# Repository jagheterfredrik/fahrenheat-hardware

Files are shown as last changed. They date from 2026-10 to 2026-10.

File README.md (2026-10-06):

# fahrenheat-hardware

A hat for the ESP32-C3 SuperMini that adds CAN-FD and 12 V input. [Firmware](https://github.com/jagheterfredrik/fahrenheat) written on Zephyr.

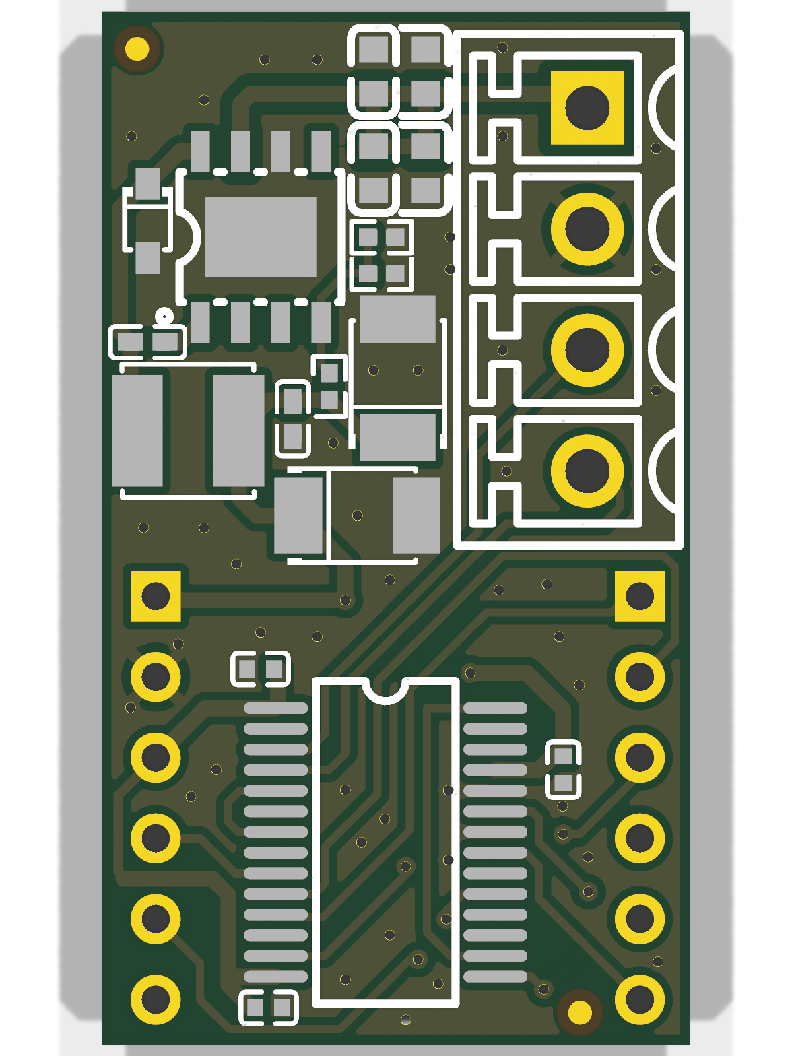
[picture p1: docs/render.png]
PCB render


- **CAN:** MCP251863 (CAN FD controller + transceiver) over SPI
- **Power:** TPS5430 buck, VCC in → 5 V to the SuperMini
- **CN1:** 3.81 mm terminal — VCC, GND, CANL, CANH

## Ordering

All parts carry LCSC numbers. `python3 export_jlcpcb.py` writes gerbers, BOM and CPL to `jlcpcb/` for JLCPCB assembly.

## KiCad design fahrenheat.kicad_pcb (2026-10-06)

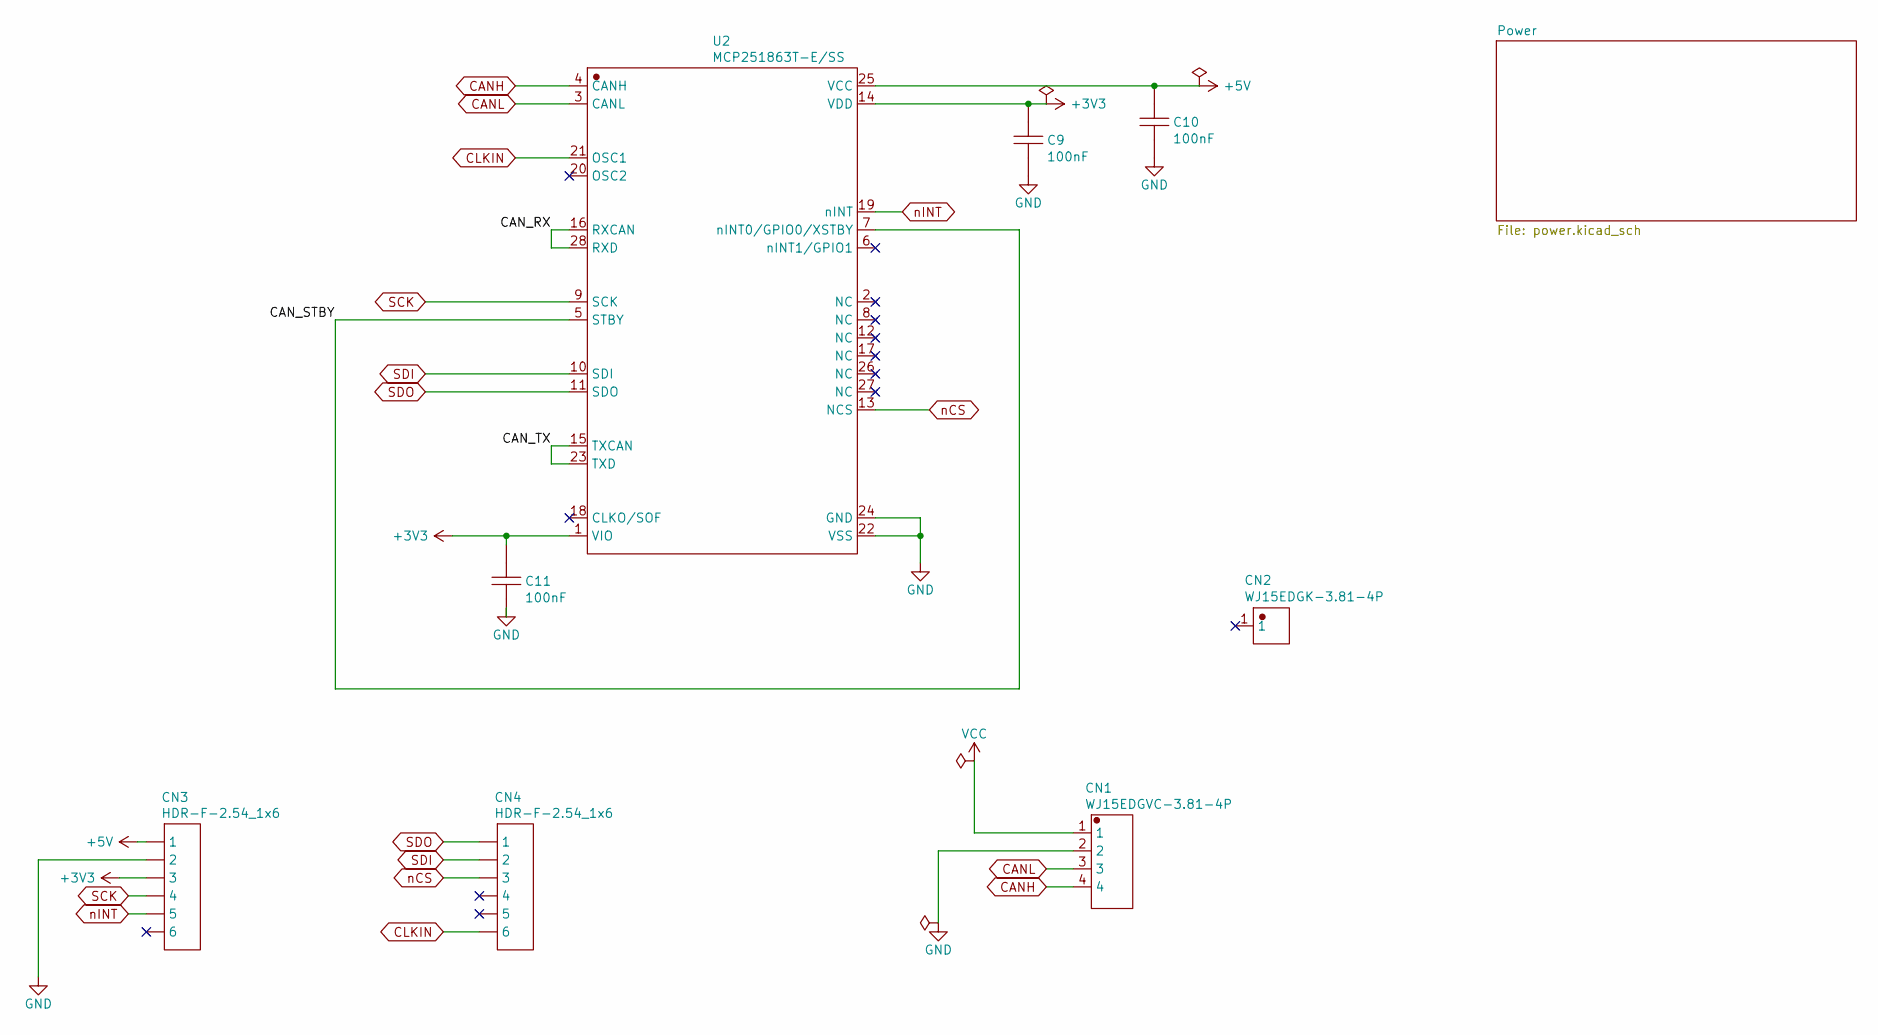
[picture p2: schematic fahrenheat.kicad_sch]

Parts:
C9, C10, C11: 100nF; C0402; MPN CL05B104KO5NNNC; LCSC C1525
CN1: WJ15EDGVC-3.81-4P; CONN-TH_4P-P3.81_WJ2EDGVC-3.81-4P; MPN WJ15EDGVC-3.81-4P; LCSC C8410
CN2: WJ15EDGK-3.81-4P; MPN WJ15EDGK-3.81-4P; LCSC C7244
CN3, CN4: HDR-F-2.54_1x6; HDR-F-2.54_1X6; LCSC C40877
U2: MCP251863T-E/SS; SSOP-28_L10.2-W5.3-P0.65-LS7.8-BL; MPN MCP251863T-E/SS; LCSC C5226885

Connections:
+3V3: C9.2, C11.2, CN3.3, U2.1 (VIO), U2.14 (VDD)
+5V: C10.2, CN3.1, U2.25 (VCC); also elsewhere on the board
/MCU_CAN/CAN_RX: U2.16 (RXCAN), U2.28 (RXD)
/MCU_CAN/CAN_STBY: U2.5 (STBY), U2.7 (nINT0/GPIO0/XSTBY)
/MCU_CAN/CAN_TX: U2.15 (TXCAN), U2.23 (TXD)
CANH: CN1.4, U2.4 (CANH)
CANL: CN1.3, U2.3 (CANL)
CLKIN: CN4.6, U2.21 (OSC1)
GND: C9.1, C10.1, C11.1, CN1.2, CN3.2, U2.22 (VSS), U2.24 (GND); also elsewhere on the board
SCK: CN3.4, U2.9 (SCK)
SDI: CN4.2, U2.10 (SDI)
SDO: CN4.1, U2.11 (SDO)
VCC: CN1.1; also elsewhere on the board
nCS: CN4.3, U2.13 (NCS)
nINT: CN3.5, U2.19 (nINT)

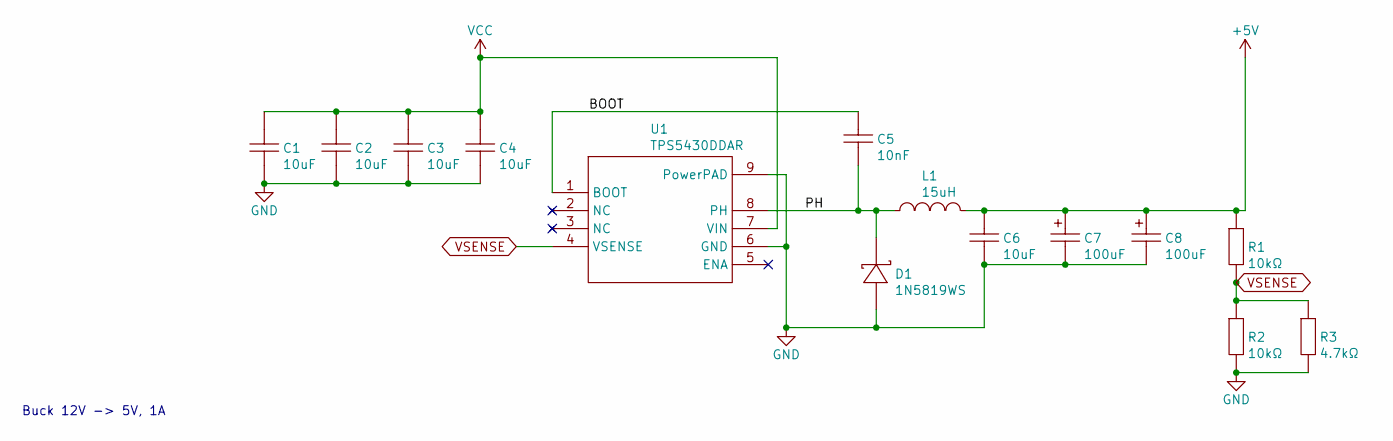
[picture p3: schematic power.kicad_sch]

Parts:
C1, C2, C3, C4: 10uF; C0603; MPN CL10A106MA8NRNC; LCSC C96446
C5: 10nF; C0402_LongPad; MPN CL05B103KB5NNNC; LCSC C15195
C6: 10uF; C0402_LongPad; MPN CL05A106MQ5NUNC; LCSC C15525
C7, C8: 100uF; CASE-B_3528; MPN TAJB107K006RNJ; LCSC C16133
D1: 1N5819WS; SOD-323_L1.8-W1.3-LS2.5-RD; MPN 1N5819WS; LCSC C191023
L1: 15uH; IND-SMD_L4.0-W4.0; MPN FHD4020S-150MT; LCSC C602033
R1, R2: 10kΩ; R0402; MPN 0402WGF1002TCE; LCSC C25744
R3: 4.7kΩ; R0402; MPN 0402WGF4701TCE; LCSC C25900
U1: TPS5430DDAR; ESOP-8_L4.9-W3.9-P1.27-LS6.0-TL-EP; MPN TPS5430DDAR; LCSC C9864

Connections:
+5V: C6.2, C7.1, C8.1, L1.2, R1.2; also elsewhere on the board
/Power/BOOT: C5.2, U1.1 (BOOT)
/Power/PH: C5.1, D1.1, L1.1, U1.8 (PH)
GND: C1.1, C2.1, C3.1, C4.1, C6.1, C7.2, C8.2, D1.2, R2.1, R3.1, U1.6 (GND), U1.9 (PowerPAD); also elsewhere on the board
VCC: C1.2, C2.2, C3.2, C4.2, U1.7 (VIN); also elsewhere on the board
VSENSE: R1.1, R2.2, R3.2, U1.4 (VSENSE)

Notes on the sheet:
Buck 12V -> 5V, 1A

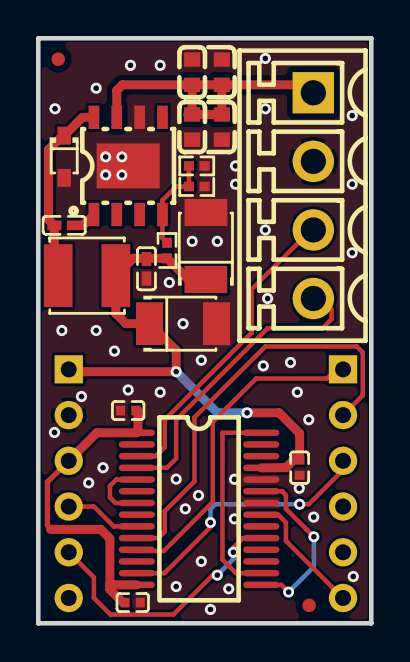
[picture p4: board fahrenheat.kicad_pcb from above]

Board: 2 copper layers, 18.5 x 32.5 mm, 23 parts (0 on the bottom side), 18 nets.

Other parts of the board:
FID1, FID2: Fiducial_0.75mm_Mask1.5mm
